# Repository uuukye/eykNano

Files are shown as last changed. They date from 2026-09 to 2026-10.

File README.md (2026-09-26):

# eykPad_nano
A small electronic pad used for timer and other cool stuff!
<br><br><br>

3D pcb image:

Screenshot 2026-09-25 at 8 32 41 PM

<br><br>
2D pcb image:

Screenshot 2026-09-25 at 8 33 00 PM

<br><br>
eykNano is a multifunctional pad. It has a RaspberryPi Pico microcontroller, and is minimalistic and compact. (67x62mm)
The microcontroller is a RaspberryPi Pico, so it has a built in Micro-USB Type-B port.

<br><br>
Schematic image:

Screenshot 2026-09-26 at 9 09 59 AM

The schematic is pretty simple. In the project, I added <b>nine</b> led lights, each with different color, <b>three</b> 
buttons (settings, next light, ok), and a 7 segment display (one digit, can allow useful features or games.

I will start with these basic three functions for this: 

-<b>A binary timer</b>. the lights represent minutes/seconds. The first light is 30 seconds, the second light is 1 minute, the third light is 2 minutes, and it doubles every light. That means you can set a timer for any multiple of 30 seconds up to 4 hours, 15 minutes and 30 seconds. When the timer is almost up (less than 10 seconds) the 7 segment LED display will count down. and once the timer ends, the LEDS flash on and off.

-<b>A memory game.</b> The nine lights will play a sequence, and you use the buttons to recreate the sequence. Like a normal memory game, it will become longer and harder over time, building up on the last sequence.

-<b>A reaction time test.</b> All the LEDS will flash on for a few seconds (randomized) and they will all turn off at the same time. The player has to press the (OK) button. Then, the lights will represent (in binary, milliseconds) how much time it took for you to press the button. (I might deduct a few milliseconds if there is a delay on pressing the button and the lights turning off)

Of course, that's not the only functions I will put for this project. I will add more cool features eventually.

<br><br>
BOM:

Screenshot 2026-09-26 at 10 34 38 AM

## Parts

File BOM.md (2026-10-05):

# eykNano — bill of materials

<!-- Generated by Half Life from project cmuurj0h409sz01sme8kw1o2r. Edits here are overwritten on the next sync. -->
<!-- Generated: 1970-01-01T00:00:00.000Z -->

> [!NOTE]
> This parts list is mirrored from [Half Life](https://halflife.hackclub.com). Editing it here will not change the platform's copy, and the next sync overwrites this file.

| Week | Tier | Parts funding |
| --- | --- | --- |
| Week 1 | Tier 1 | $30.00 |

_No parts listed yet._

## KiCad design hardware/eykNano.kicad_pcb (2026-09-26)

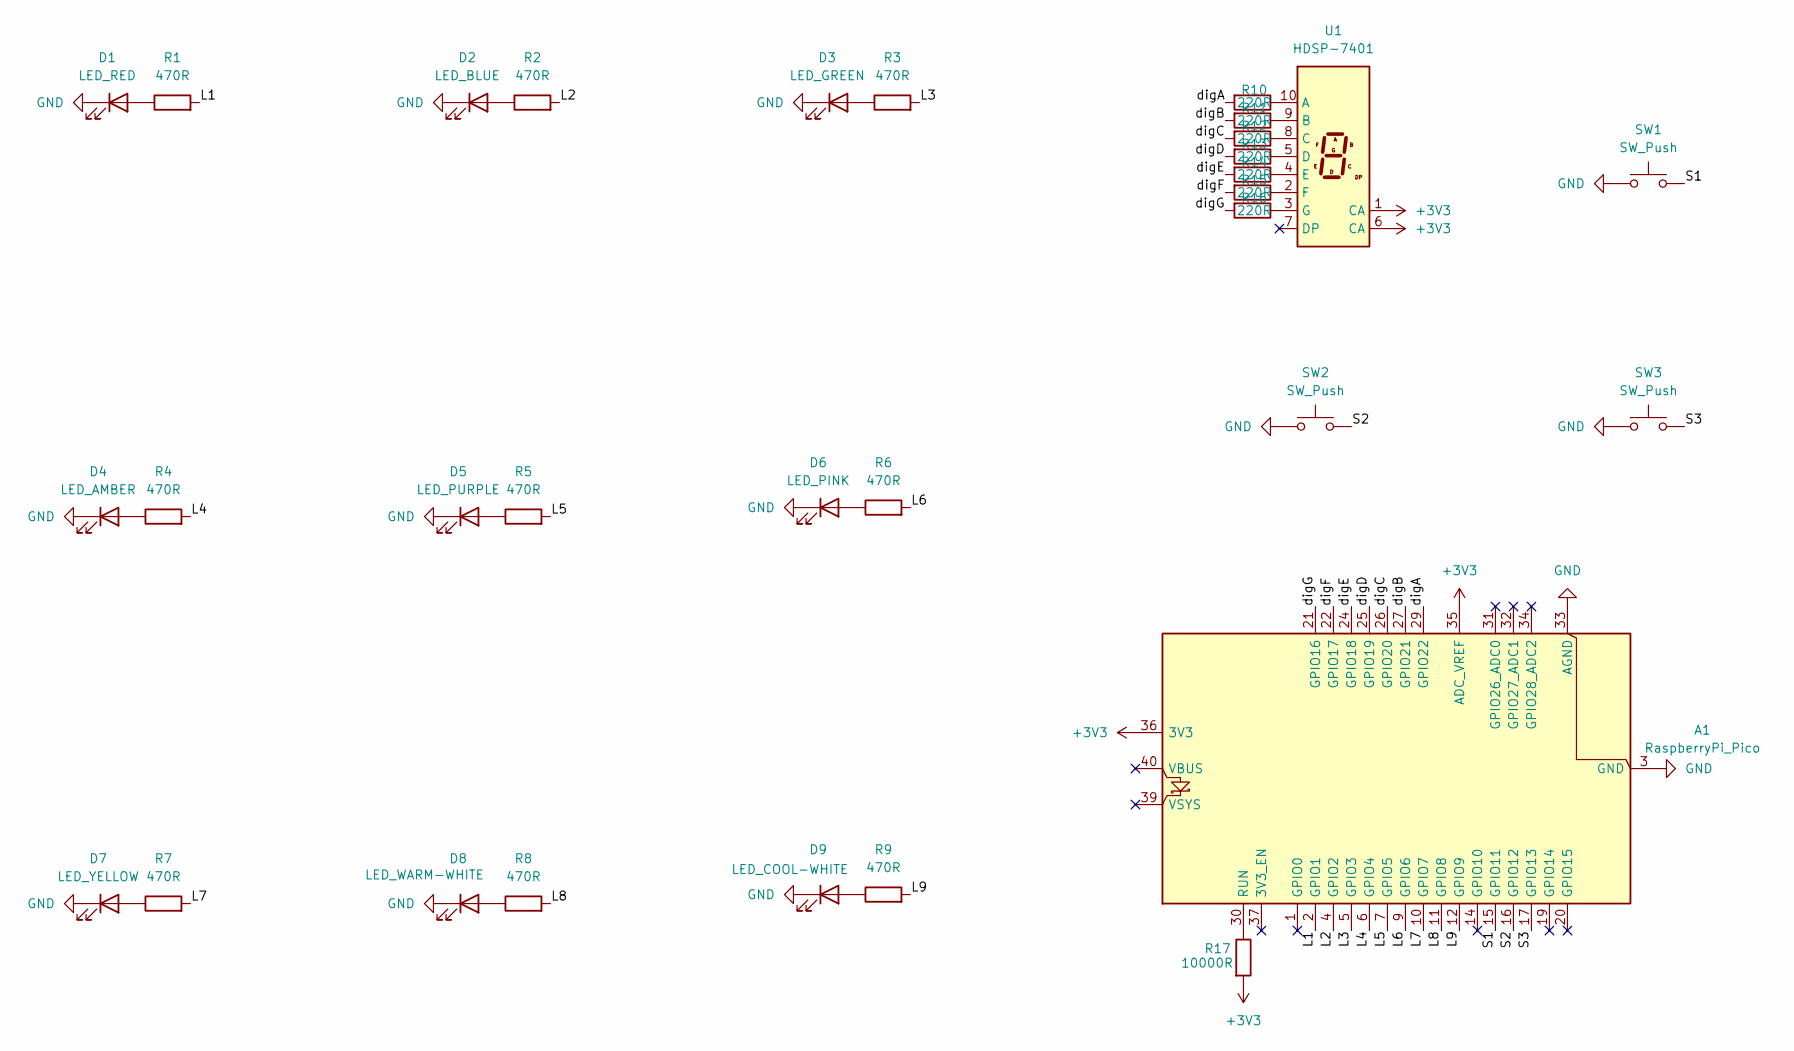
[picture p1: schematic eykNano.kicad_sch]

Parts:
A1: RaspberryPi_Pico; RaspberryPi_Pico_SMD_HandSolder
D1: LED_RED; LED_0805_2012Metric
D2: LED_BLUE; LED_0805_2012Metric
D3: LED_GREEN; LED_0805_2012Metric
D4: LED_AMBER; LED_0805_2012Metric
D5: LED_PURPLE; LED_0805_2012Metric
D6: LED_PINK; LED_0805_2012Metric
D7: LED_YELLOW; LED_0805_2012Metric
D8: LED_WARM-WHITE; LED_0805_2012Metric
D9: LED_COOL-WHITE; LED_0805_2012Metric
R1, R2, R3, R4, R5, R6, R7, R8, R9: 470R; R_0805_2012Metric
R10, R11, R12, R13, R14, R15, R16: 220R; R_0805_2012Metric
R17: 10000R; R_0805_2012Metric
SW1, SW2, SW3: SW_Push; SW_Push_1P1T_NO_E-Switch_TL3301NxxxxxG
U1: HDSP-7401

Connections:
+3V3: A1.35 (ADC_VREF), A1.36 (3V3), R17.2, U1.1 (CA), U1.6 (CA)
/L1: A1.2 (GPIO1), R1.2
/L2: A1.4 (GPIO2), R2.2
/L3: A1.5 (GPIO3), R3.2
/L4: A1.6 (GPIO4), R4.2
/L5: A1.7 (GPIO5), R5.2
/L6: A1.9 (GPIO6), R6.2
/L7: A1.10 (GPIO7), R7.2
/L8: A1.11 (GPIO8), R8.2
/L9: A1.12 (GPIO9), R9.2
/S1: A1.15 (GPIO11), SW1.2
/S2: A1.16 (GPIO12), SW2.2
/S3: A1.17 (GPIO13), SW3.2
/digA: A1.29 (GPIO22), R10.2
/digB: A1.27 (GPIO21), R11.2
/digC: A1.26 (GPIO20), R12.2
/digD: A1.25 (GPIO19), R13.2
/digE: A1.24 (GPIO18), R14.2
/digF: A1.22 (GPIO17), R15.2
/digG: A1.21 (GPIO16), R16.2
GND: A1.3 (GND), A1.8 (GND), A1.13 (GND), A1.18 (GND), A1.23 (GND), A1.28 (GND), A1.33 (AGND), A1.38 (GND), D1.1 (K), D2.1 (K), D3.1 (K), D4.1 (K), D5.1 (K), D6.1 (K), D7.1 (K), D8.1 (K), D9.1 (K), SW1.1, SW2.1, SW3.1
unnamed: A1.30 (RUN), R17.1
unnamed: D1.2 (A), R1.1
unnamed: D2.2 (A), R2.1
unnamed: D3.2 (A), R3.1
unnamed: D4.2 (A), R4.1
unnamed: D5.2 (A), R5.1
unnamed: D6.2 (A), R6.1
unnamed: D7.2 (A), R7.1
unnamed: D8.2 (A), R8.1
unnamed: D9.2 (A), R9.1
unnamed: R10.1, U1.10 (A)
unnamed: R11.1, U1.9 (B)
unnamed: R12.1, U1.8 (C)
unnamed: R13.1, U1.5 (D)
unnamed: R14.1, U1.4 (E)
unnamed: R15.1, U1.2 (F)
unnamed: R16.1, U1.3 (G)

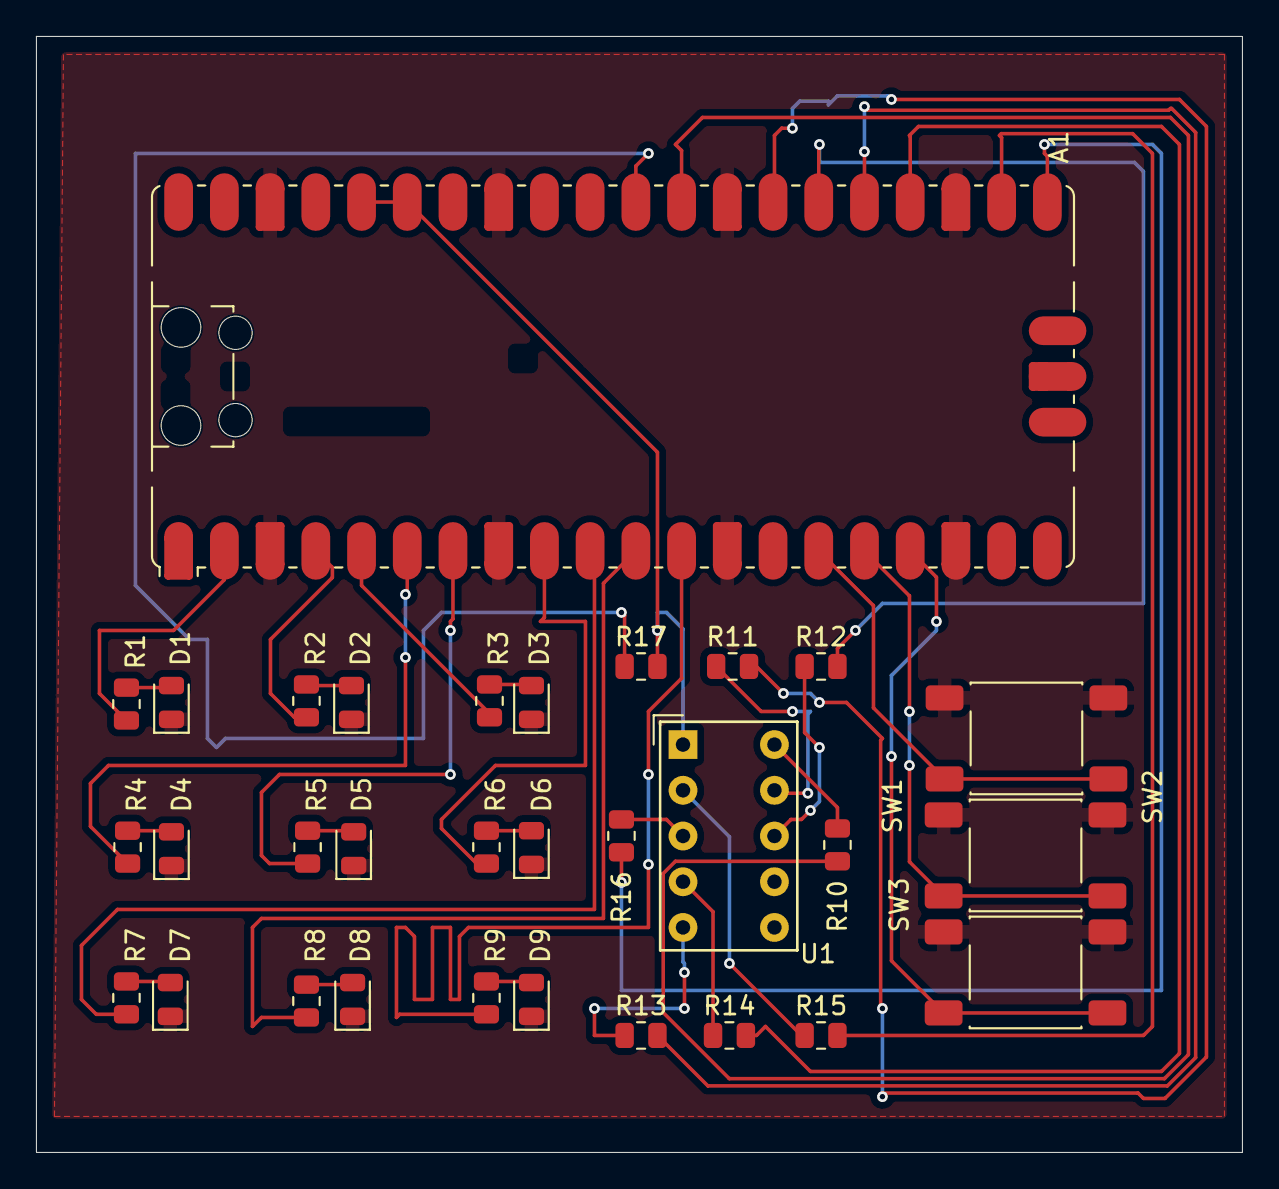
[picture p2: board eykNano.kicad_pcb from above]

Board: 2 copper layers, 67.0 x 62.0 mm, 31 parts (0 on the bottom side), 38 nets.

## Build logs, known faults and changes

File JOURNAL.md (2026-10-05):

# eykNano — devlog

<!-- Generated by Half Life from project cmuurj0h409sz01sme8kw1o2r. Edits here are overwritten on the next sync. -->
<!-- Generated: 1970-01-01T00:00:00.000Z -->

> [!NOTE]
> This devlog is mirrored from [Half Life](https://halflife.hackclub.com). Editing it here will not change the platform's copy, and the next sync overwrites this file.

| Week | Tier | Hours logged | Entries |
| --- | --- | --- | --- |
| Week 1 | Tier 1 | 0h | 0 |

_No entries logged yet._

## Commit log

2026-09-26 Update README with PCB and schematic images
    Added images of 3D PCB, 2D PCB, and schematic to README.
2026-09-26 Update README with project details and images
    Added images and details about the eykPad_nano project, including PCB and schematic images.
2026-09-26 Update README with BOM and new images
    Added BOM section and additional images to README.
